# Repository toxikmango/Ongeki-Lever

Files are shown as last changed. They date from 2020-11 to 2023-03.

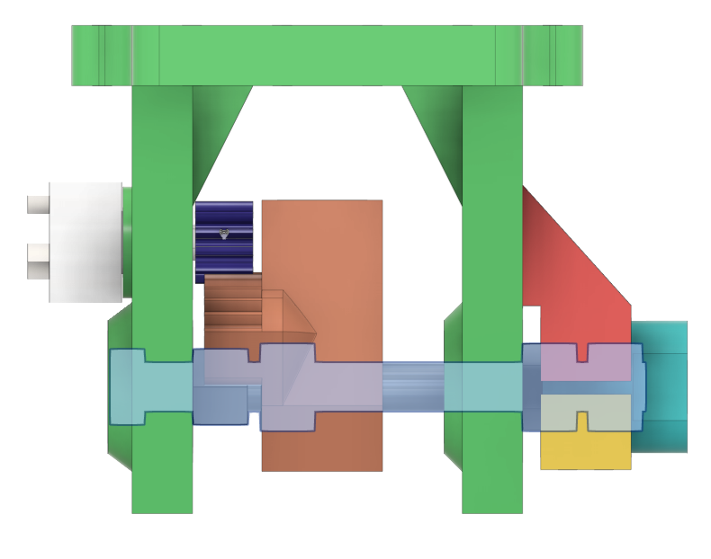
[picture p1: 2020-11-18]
Ongeki lever 3d printed/photos/General assembly side.png

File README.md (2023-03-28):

# Ongeki-Lever
A 3D printable ongeki lever using 5/16" and M3 fasteners

Print at your own risk (my printer tolerance will be different than yours). I'm not responsible for wasted filament. 
Use the test prints to adjust scaling (+/-%) 
to get things to fit.

Designed to use this encoder 
20mm Contactless Digitized Potentiometer 6mm shaft 0-5v
https://amzn.to/3eXmKgd

Printed with 3 perimeters, top, and bottom layers with 15% infill. 

--Uses 5/16" hardware
--5/16" fully threaded bolt for the handle (5.5-6" long)
--5/16" fully threaded for the pivot rod (about 3.75"-4" long)
--5/16" nylock nuts (4)
--608 skateboard bearings (2 of them) (8mm ID, 22mm OD, 7mm thick)
--m3 bolts and nuts to attach the top and bottom clamp together. (35mm long)
--m3 bolts can be used to attach the assembly to the controller body or #6 screws countersunk from the top of the controller going down into the lever assembly mounting holes. (Length depends on your wood thickness but I used 3/4" long screws.) 
--Dielectric grease

I didn't personally do this on mine, but you could put dielectric grease or something similar between the "tension chuck" and the "top/bottom clamp's" mating surfaces.
Also, you may want to sand the "tension chuck" and possibly the mating faces of the clamps. Again, I didn't do this for mine. 
You can also add some sort of lubricant on the gear teeth.

If parts don't press fit in suuuuper snug, you could use some glue. Assembly should need no adhesives. Maybe a few drops of CA glue holding the top clamp to the body, but that's really it.

Print at your own risk (my printer tolerance will be different than yours). I'm not responsible for wasted filament. 
Use the test prints to adjust scaling (+/-%) 
to get things to fit.

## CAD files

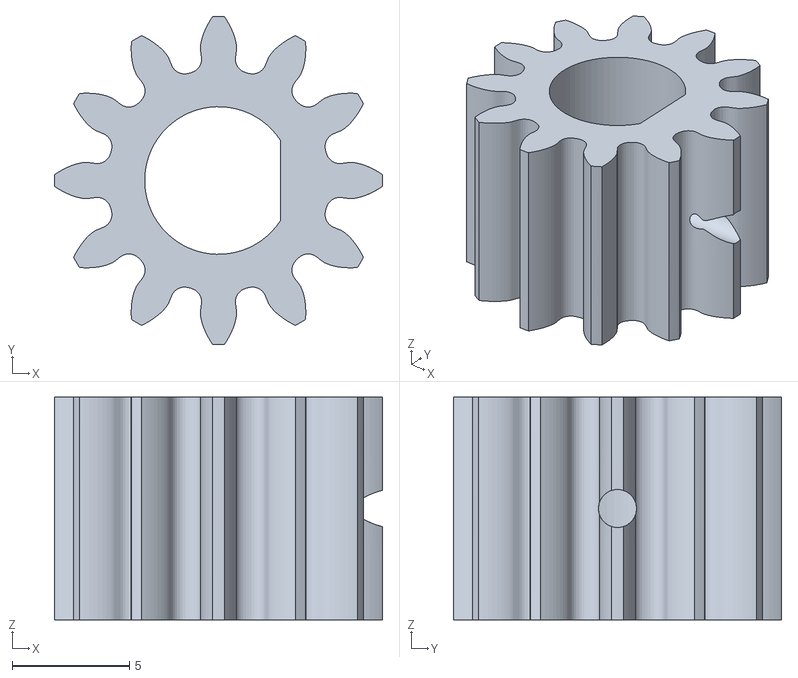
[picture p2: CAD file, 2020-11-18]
Ongeki lever 3d printed/Test prints for calibration/Spur Gear (12 teeth).stl
14.0 x 14.0 x 9.50

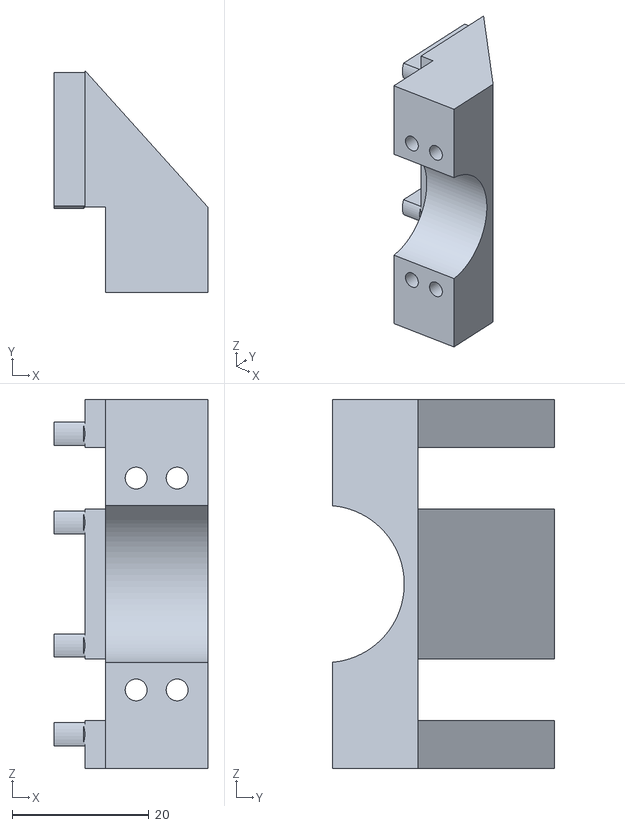
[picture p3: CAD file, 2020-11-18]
Ongeki lever 3d printed/top clamp.stl
22.5 x 32.5 x 54.0

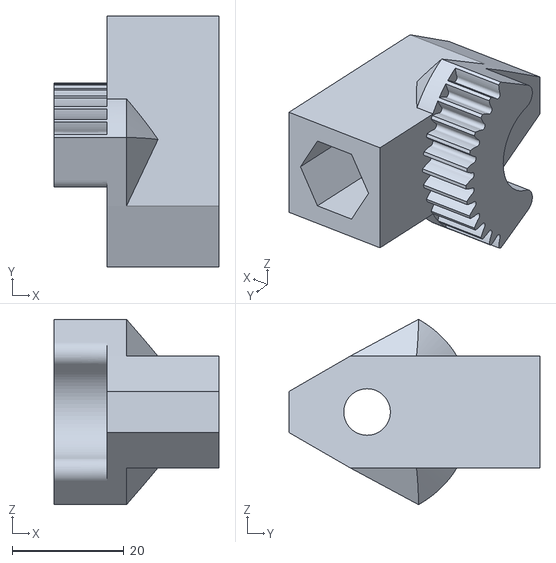
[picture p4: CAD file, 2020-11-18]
Ongeki lever 3d printed/lever.stl
29.5 x 45.0 x 33.2

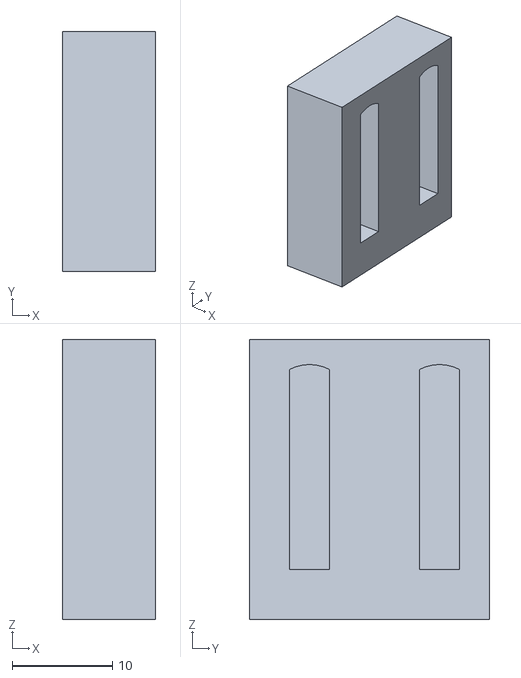
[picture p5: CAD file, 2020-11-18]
Ongeki lever 3d printed/Test prints for calibration/top clamp female section.stl
9.35 x 24.0 x 28.0

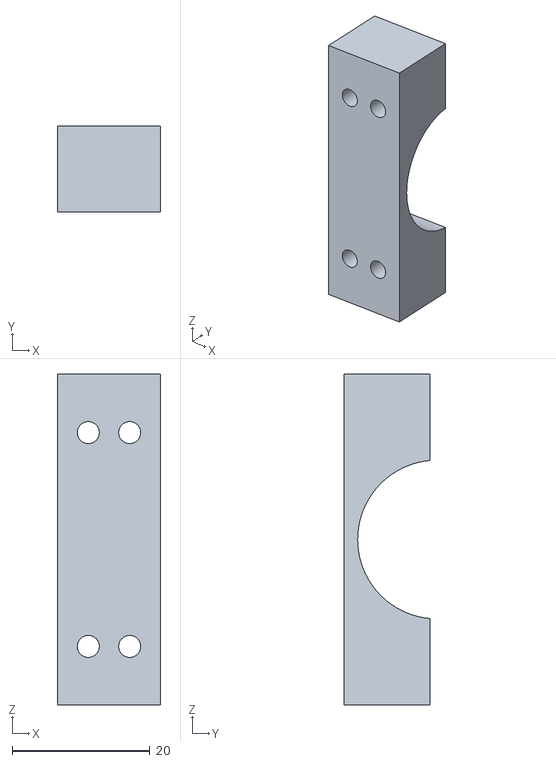
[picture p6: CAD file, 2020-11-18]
Ongeki lever 3d printed/bottom clamp.stl
15.0 x 12.5 x 48.0

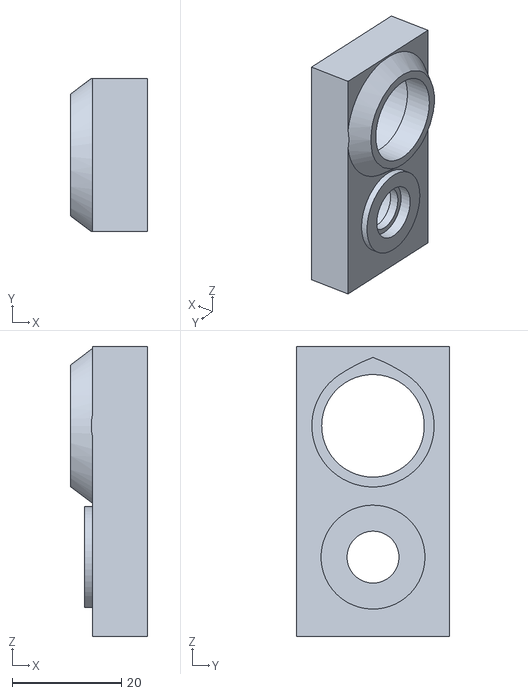
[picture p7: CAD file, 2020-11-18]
Ongeki lever 3d printed/Test prints for calibration/bearing and encoder.stl
14.0 x 28.0 x 53.0

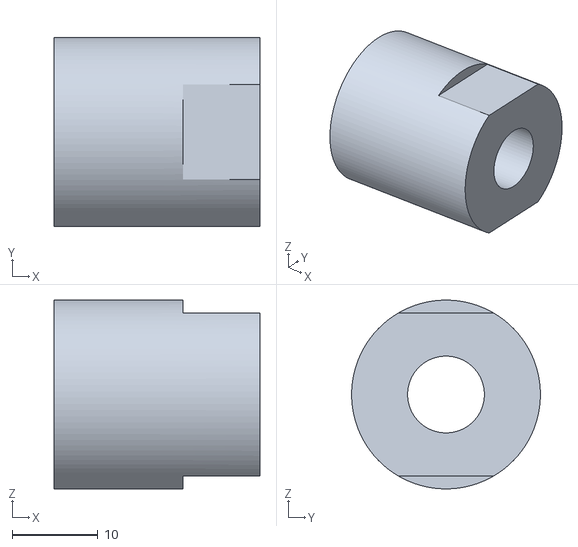
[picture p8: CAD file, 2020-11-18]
Ongeki lever 3d printed/tension chuck.stl
24.0 x 22.0 x 22.0

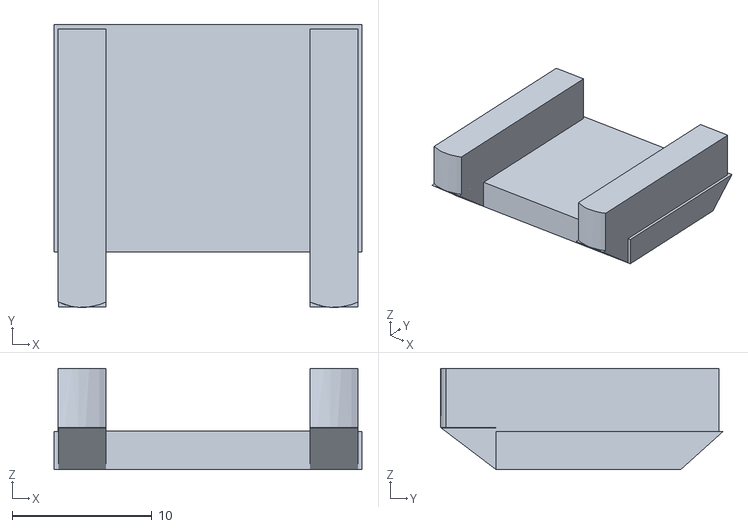
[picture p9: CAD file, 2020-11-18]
Ongeki lever 3d printed/Test prints for calibration/top clamp male section.stl
22.0 x 20.2 x 7.25

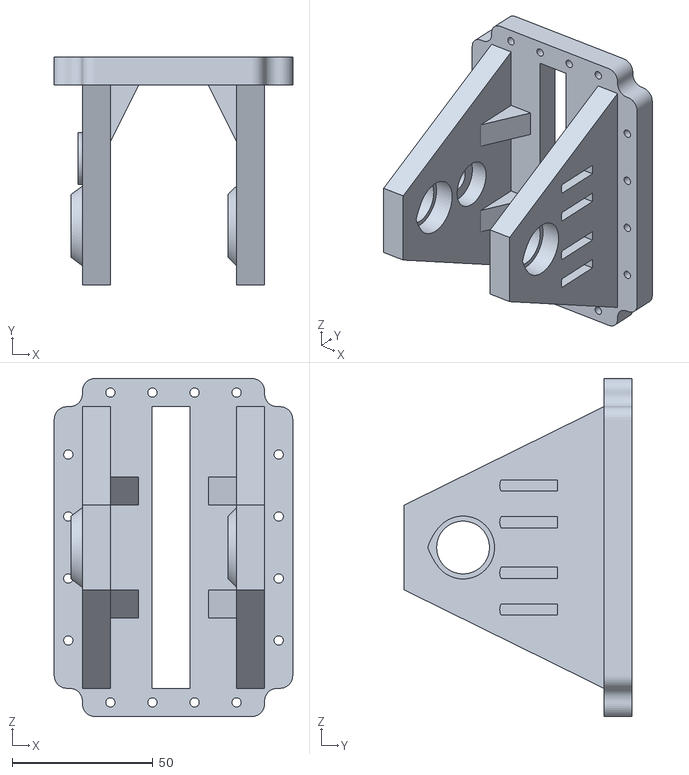
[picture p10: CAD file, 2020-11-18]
Ongeki lever 3d printed/base.stl
84.7 x 81.0 x 120.0

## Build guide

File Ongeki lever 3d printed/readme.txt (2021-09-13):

# Ongeki-Lever
A 3D printable ongeki lever using 5/16" and M3 fasteners

Print at your own risk (my printer tolerance will be different than yours). I'm not responsible for wasted filament. 
Use the test prints to adjust scaling (+/-%) 
to get things to fit.

Designed to use this encoder 
20mm Contactless Digitized Potentiometer 6mm shaft 0-5v
https://amzn.to/3eXmKgd

Printed with 3 perimeters, top, and bottom layers with 15% infill. 

--Uses 5/16" hardware
--5/16" fully threaded bolt for the handle (5.5-6" long)
--5/16" fully threaded for the pivot rod (about 3.75"-4" long)
--5/16" nylock nuts (4)
--608 skateboard bearings (2 of them) (8mm ID, 22mm OD, 7mm thick)
--m3 bolts and nuts to attach the top and bottom clamp together. (35mm long)
--m3 bolts can be used to attach the assembly to the controller body or #6 screws countersunk from the top of the controller going down into the lever assembly mounting holes. (Length depends on your wood thickness but I used 3/4" long screws.) 
--Dielectric grease

I didn't personally do this on mine, but you could put dielectric grease or something similar between the "tension chuck" and the "top/bottom clamp's" mating surfaces.
Also, you may want to sand the "tension chuck" and possibly the mating faces of the clamps. Again, I didn't do this for mine. 
You can also add some sort of lubricant on the gear teeth. I used GPL 105 lubricant (oil based lubricant) as I have it on  hand from lubing keyboard switches. But I think something light would be better than a thick grease based lubricant, but feel free to try what you want.  

If parts don't press fit in suuuuper snug, you could use some glue. Assembly should need no adhesives. Maybe a few drops of CA glue holding the top clamp to the body, but that's really it.

Print at your own risk (my printer tolerance will be different than yours). I'm not responsible for wasted filament. 
Use the test prints to adjust scaling (+/-%) 
to get things to fit.

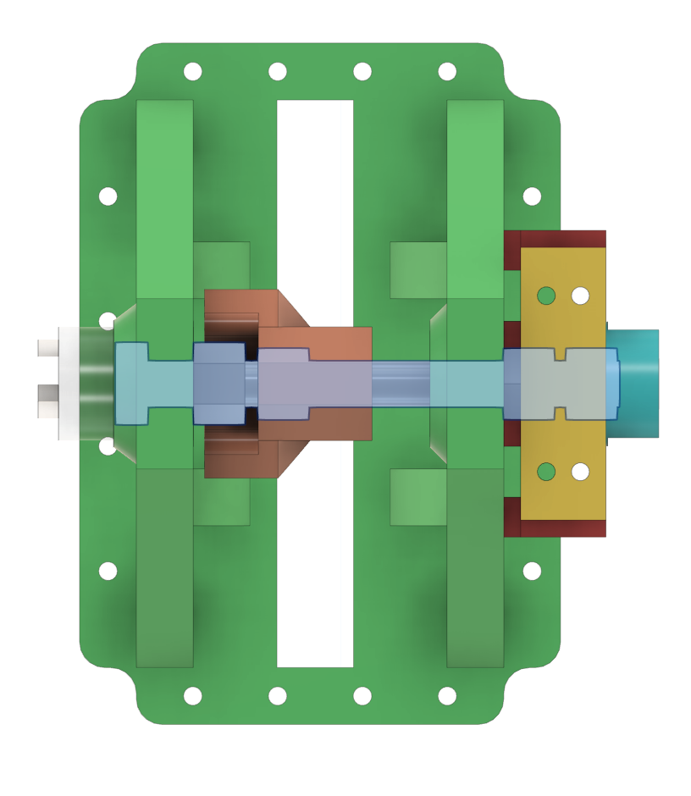
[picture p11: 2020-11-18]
Ongeki lever 3d printed/photos/general assembly bottom.png

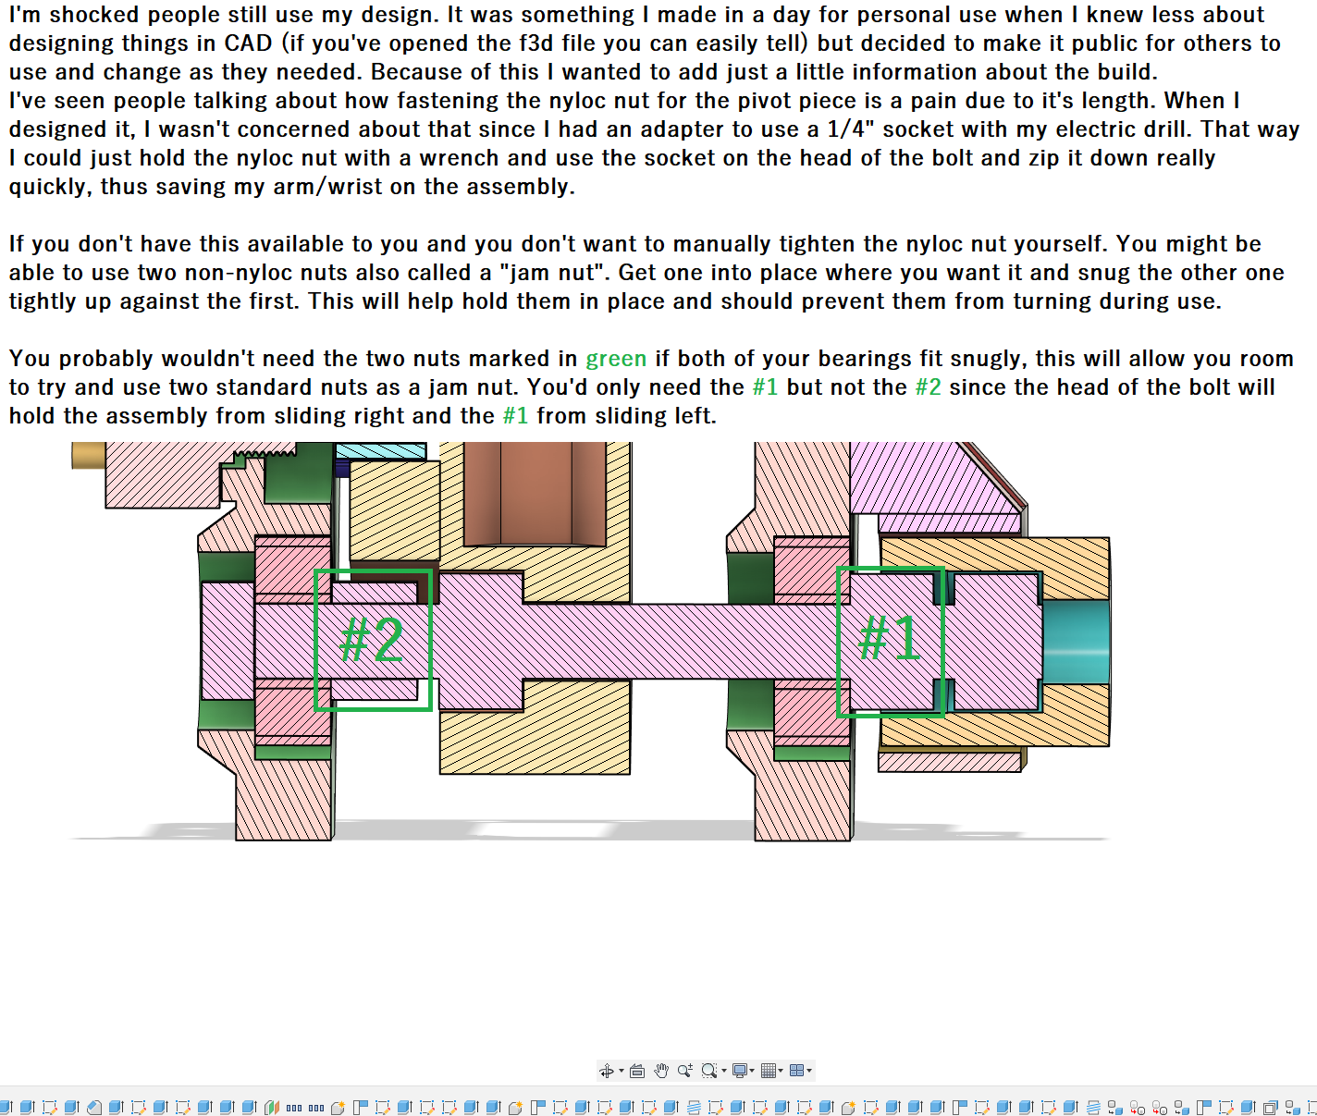
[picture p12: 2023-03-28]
Ongeki lever 3d printed/photos/jam nut explanation.png

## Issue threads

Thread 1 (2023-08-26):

how to solve no damping problem

superboy724, 2023-08-26:
I successfully assembled the controller components, but there is no damping. How can I solve this problem?

toxikmango, 2023-08-27:
Hello. Tightening the clamps around the chuck is what provides the damping. If the clamp is fully tightened and you get no added resistance to your lever it might have to do with your printer tolerances.
You could also add thick grease, something like silicone grease might work, or if you can find it, damping grease. Years later and while I'm sure my pla printed chuck/clamp parts have slightly deformed, the controller still functions fine and I can play my usual level in game without issues.

On the Cons&Stuff discord, there is another user in the ongeki section that made a lever design replicating the official cab hardware. You could always try that, but I found some of the parts hard to source (mainly the spring).

superboy724, 2023-09-02:
> Hello. Tightening the clamps around the chuck is what provides the damping. If the clamp is fully tightened and you get no added resistance to your lever it might have to do with your printer tolerances. You could also add thick grease, something like silicone grease might work, or if you can find it, damping grease. Years later and while I'm sure my pla printed chuck/clamp parts have slightly deformed, the controller still functions fine and I can play my usual level in game without issues.
>
> On the Cons&Stuff discord, there is another user in the ongeki section that made a lever design replicating the official cab hardware. You could always try that, but I found some of the parts hard to source (mainly the spring).

thanks,i just fixed this problem,my assembling method is incorrect in  4-inch pivot rod

Closed 2023-09-02.

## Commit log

2020-11-18 Added files
    Added current files
    [Spur Gear (12 teeth).stl, base.stl, bearing and encoder.stl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]
2020-11-18 Outline
    Print at your own risk (my printer tolerance will be different than yours). I'm not responsible for wasted filament. Use the test prints to adjust scaling (+/-%) to get things to fit.
    Designed to use this encoder
    20mm Contactless Digitized Potentiometer 6mm shaft 0-5v
    https://amzn.to/3eXmKgd
    Printed with 3 perimeters, top, and bottom layers with 15% infill.
    --Uses 5/16" hardware
    --5/16" fully threaded bolt for the handle (5.5-6" long)
    --5/16" fully threaded for the pivot rod (about 3.75"-4" long)
    --5/16" nylock nuts (4)
    --608 skateboard bearings (2 of them) (8mm ID, 22mm OD, 7mm thick)
    --m3 bolts and nuts to attach the top and bottom clamp together. (35mm long)
    --m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
2023-03-28 Added new explanation photo
    Added a photo explaining the use of a jam nut instead of the nyloc nut that holds the lever arm in place.
